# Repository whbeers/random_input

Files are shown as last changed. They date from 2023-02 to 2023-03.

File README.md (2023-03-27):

# Random Input Fuzz Effect

This is a re-creation of the original Dallas Arbiter Fuzz Face effect circuit, continuing my attempts to design guitar effects using [KiCAD](https://www.kicad.org/).

The resulting design is a product of breadboarding and experimentation after an initial build of the original circuit. It emphasizes the ability to easily fine-tune the bias of each transistor to obtain a pleasant sound from a variety of NPN transistors (germanium or silicon). Besides this emphasis, it remains true to the original.

The board is built on the ["Noise Floor"](https://github.com/whbeers/noise_floor) pedal platform, which provides basic power protection, audio IO, and a footswitch with LED indicator.

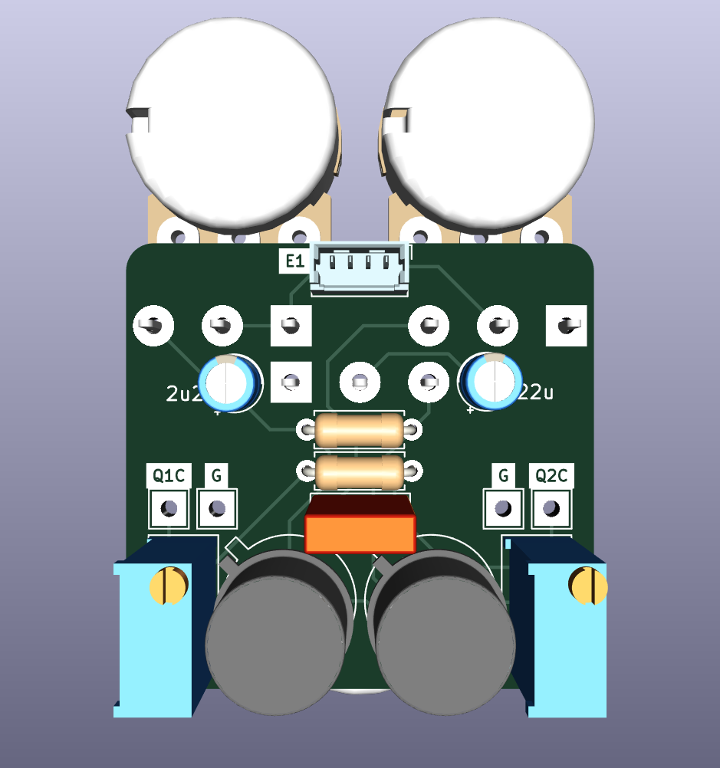
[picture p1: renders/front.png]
Front render

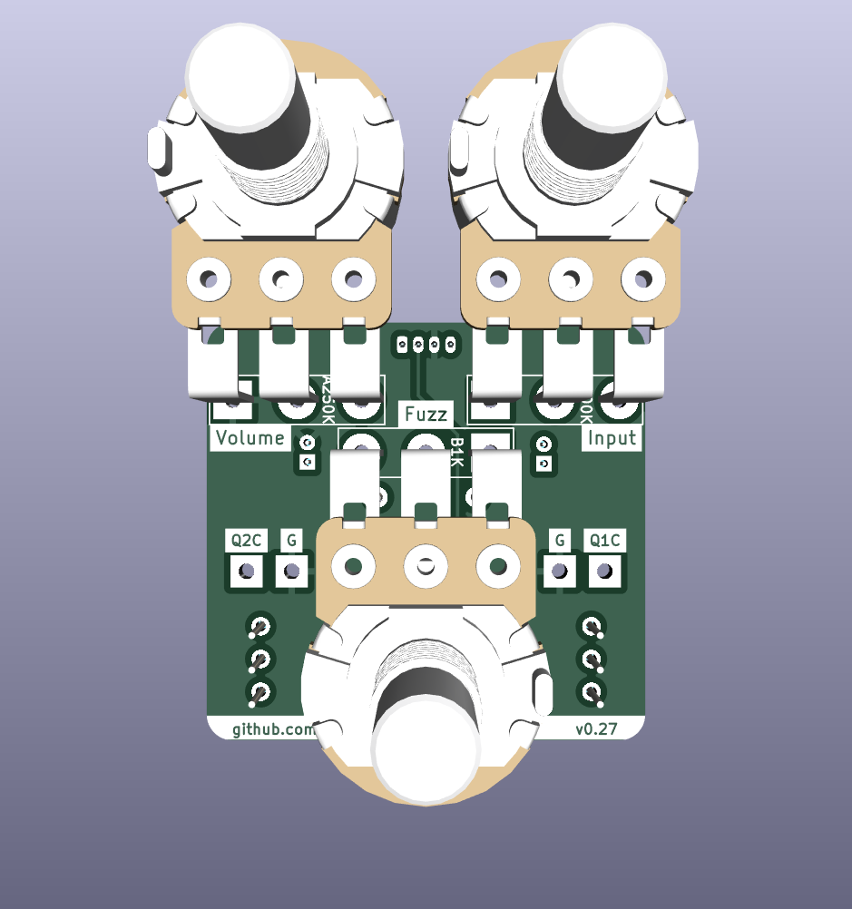
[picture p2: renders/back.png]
Back render

Schematic SVG
[Schematic PDF](schematics/random_input-latest.pdf)

Instructions for biasing transistors (using the incorporated trimpots) are provided in the schematic. (This was the approach that worked for me, after a few hours of research. I'm by no means an expert and would welcome feedback.)

## Credit
The basic schematic I worked from is widely available on the internet. At the same time my research drew on analyses from far-greater experts than myself, as well as published circuit diagrams. Most notably:
 - [CODA Effects' circuit analysis](https://www.coda-effects.com/p/circuit-analysis-fuzz-face.html)
 - [RG Keen's analysis](http://www.geofex.com/article_folders/fuzzface/fffram.htm)
 - [PedalPCB Twin Face](https://www.pedalpcb.com/product/twinface/)

Thanks as always to the folks on the [freestompboxes.org](https://www.freestompboxes.org/) forum for feedback and suggestions.

Potentiometer 3D model courtesy [Vasily Kashirin](https://grabcad.com/vasily.kashirin-1).

*I am not affiliated with any of the brands, sites, or products named in this overview.*

## Versioning

My pcb designs utilize the following versioning scheme (I'll add to this as I produce more revisions):
 - v0.0XX: A candidate design that has not yet been produced and tested.
 - v0.XX: A design that has been produced, tested, and any initial errors addressed.

## Name
*The name "Random Input" is a reflection of the nature of the effect (a very basic fuzz) and security nerdery (fuzzing software using random input being a primitive technique to surface errors).*

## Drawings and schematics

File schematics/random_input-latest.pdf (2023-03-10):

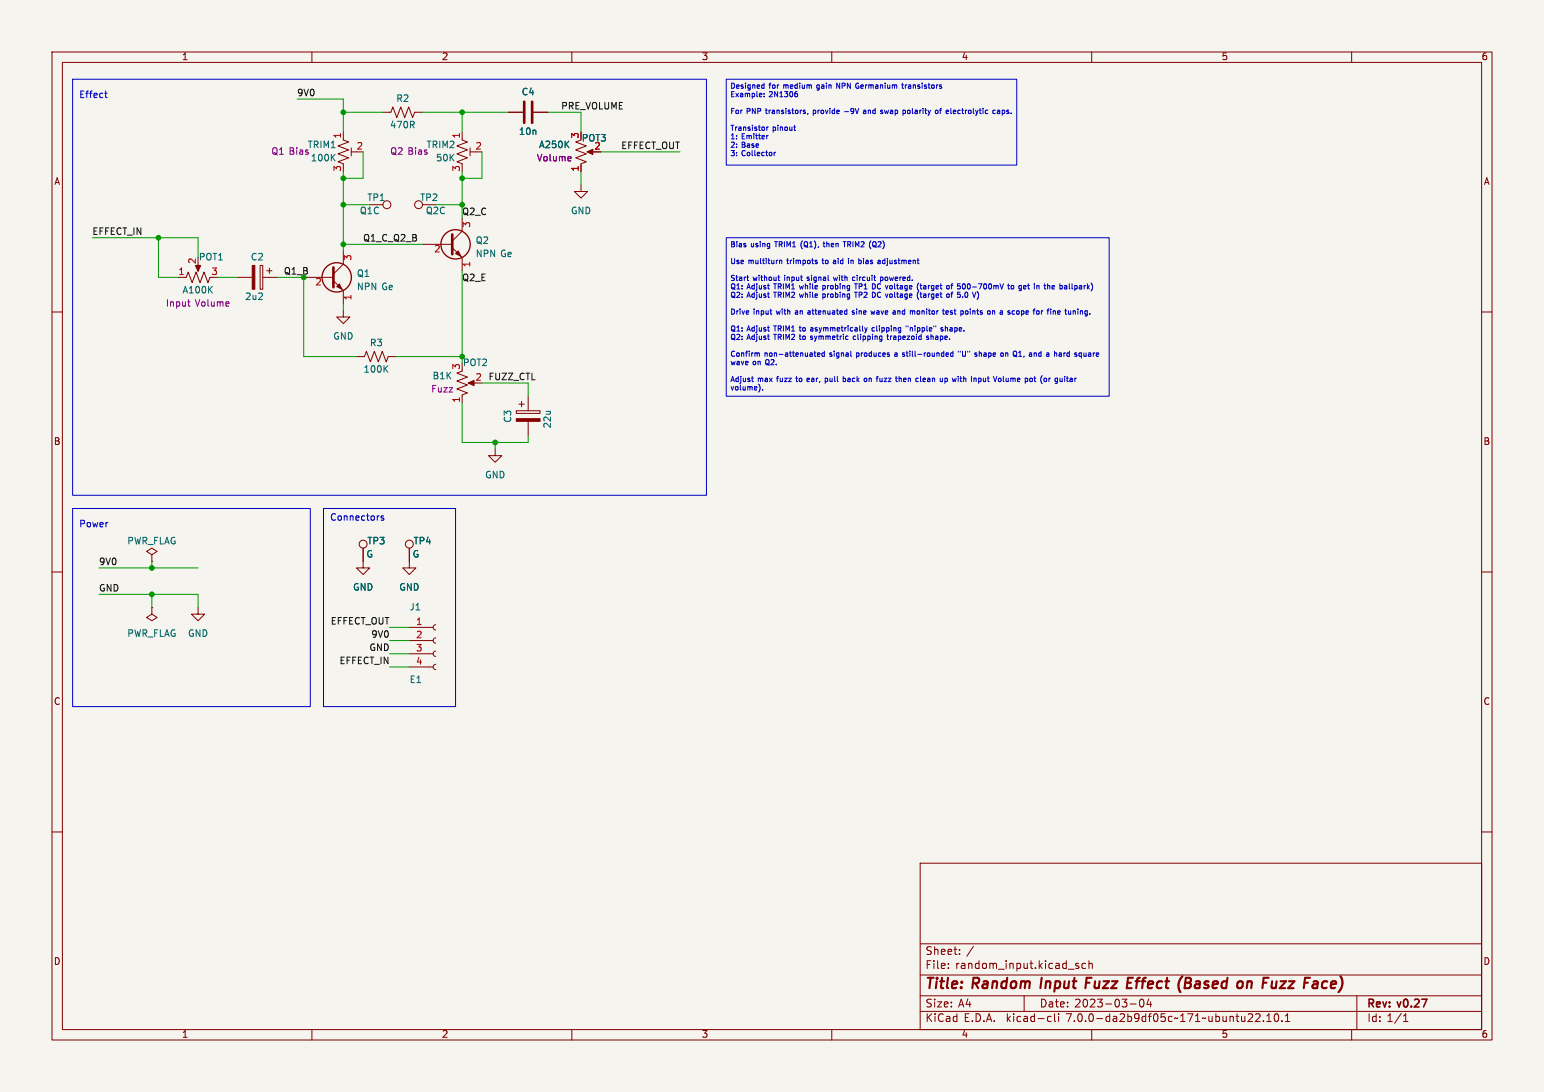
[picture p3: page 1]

Id: 1/1 Title: Random Input Fuzz Effect (Based on Fuzz Face) File: random_input.kicad_sch Sheet: /

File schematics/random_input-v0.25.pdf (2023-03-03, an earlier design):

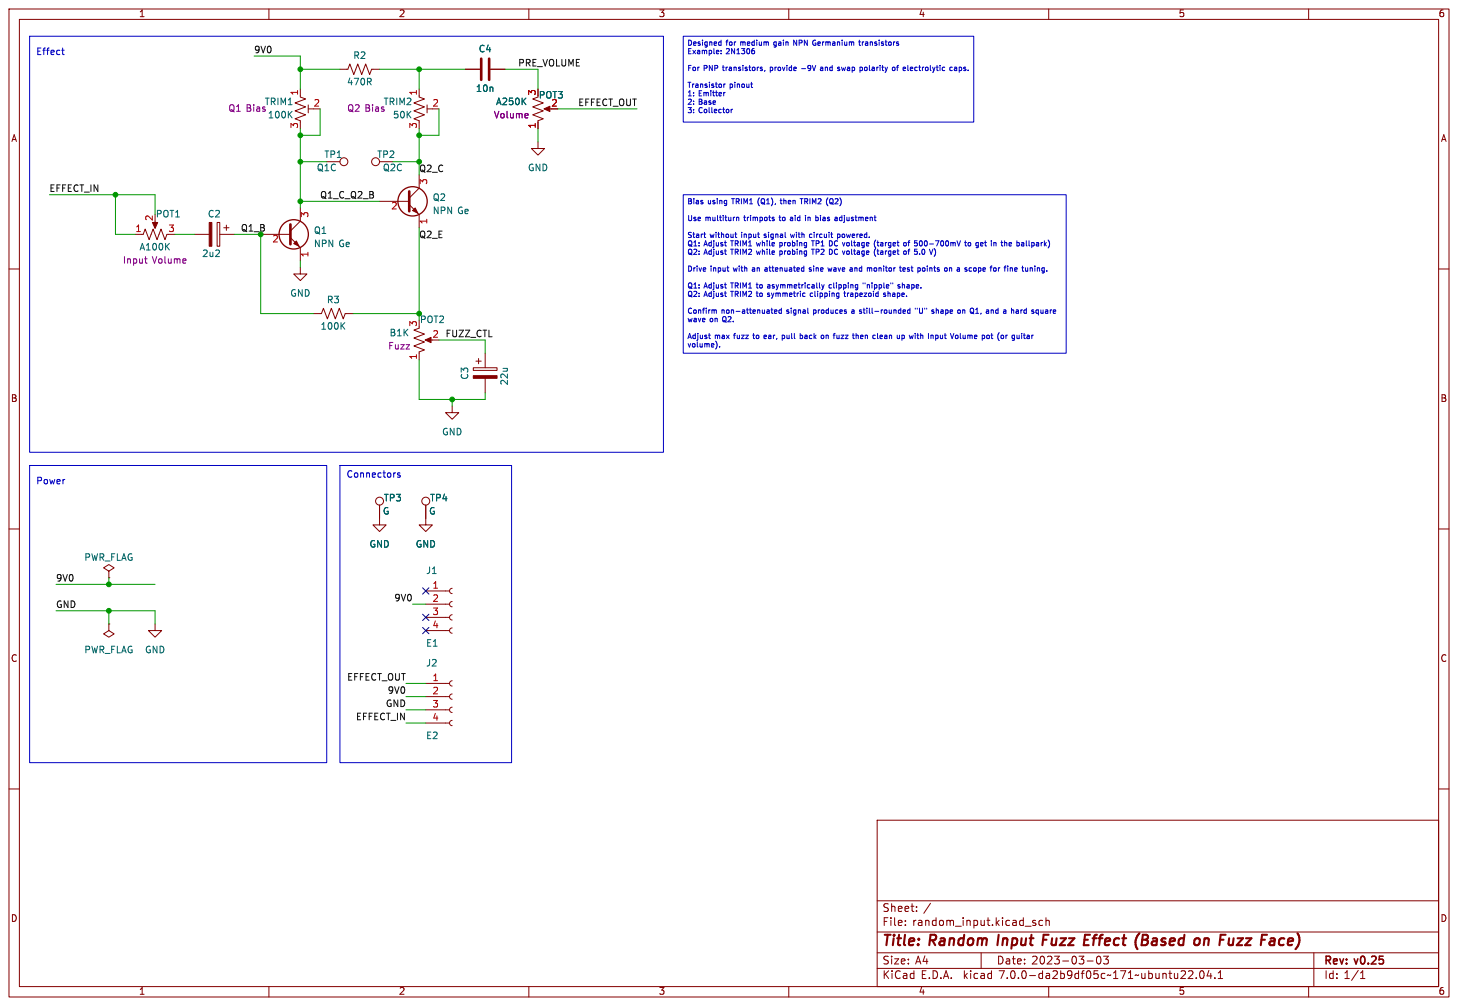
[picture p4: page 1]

Id: 1/1 Title: Random Input Fuzz Effect (Based on Fuzz Face) File: random_input.kicad_sch Sheet: /

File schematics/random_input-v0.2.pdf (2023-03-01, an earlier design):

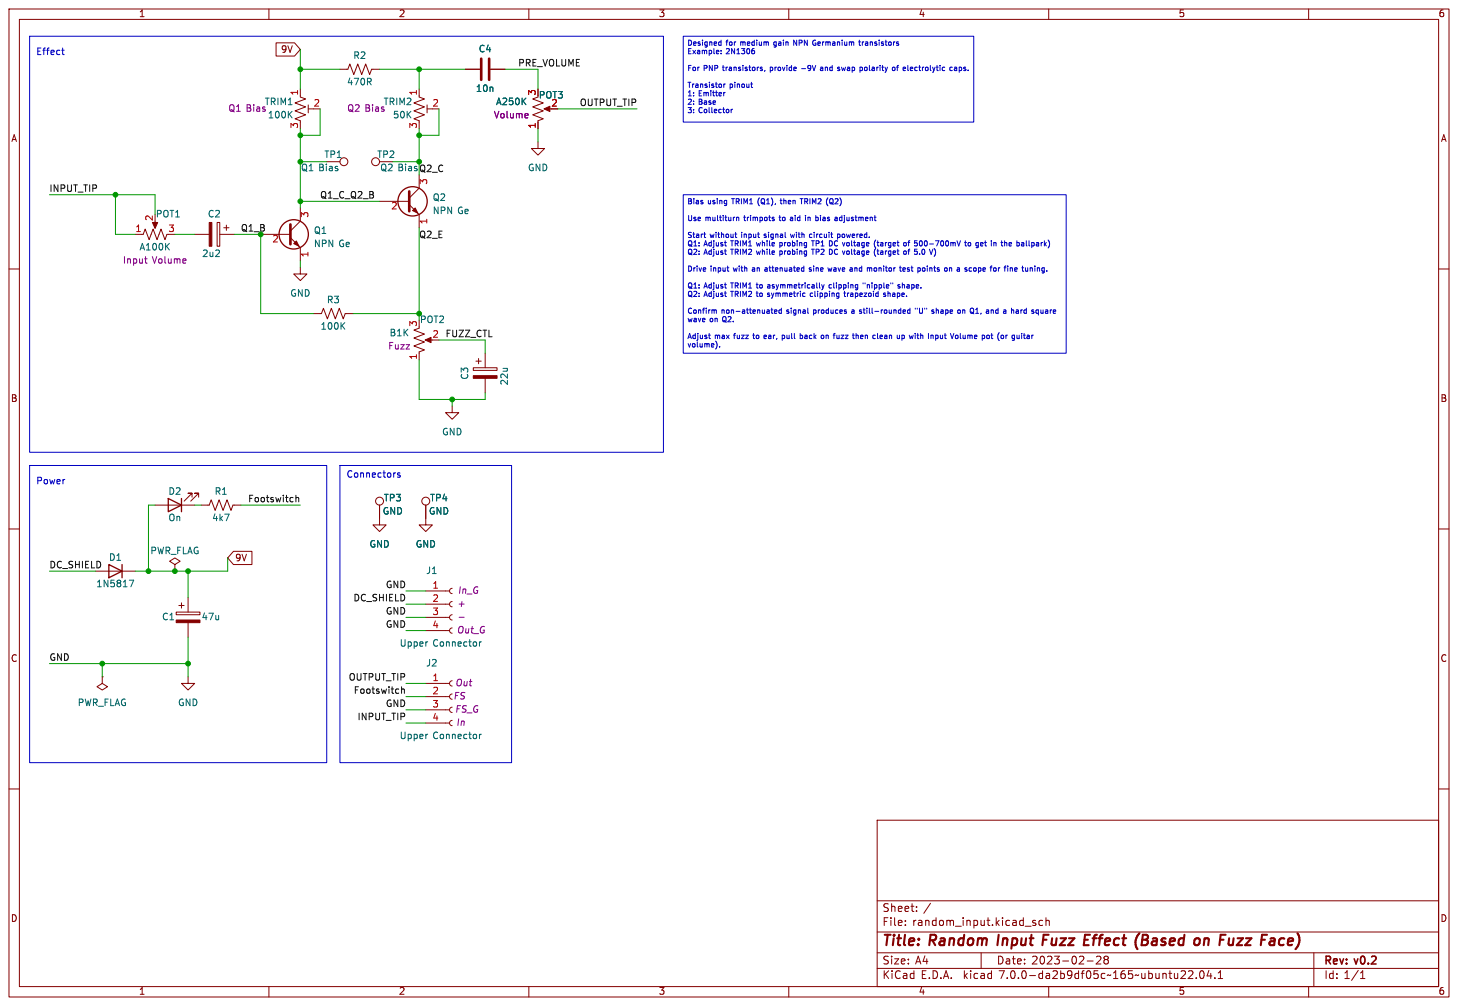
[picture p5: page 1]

Id: 1/1 Title: Random Input Fuzz Effect (Based on Fuzz Face) File: random_input.kicad_sch Sheet: /

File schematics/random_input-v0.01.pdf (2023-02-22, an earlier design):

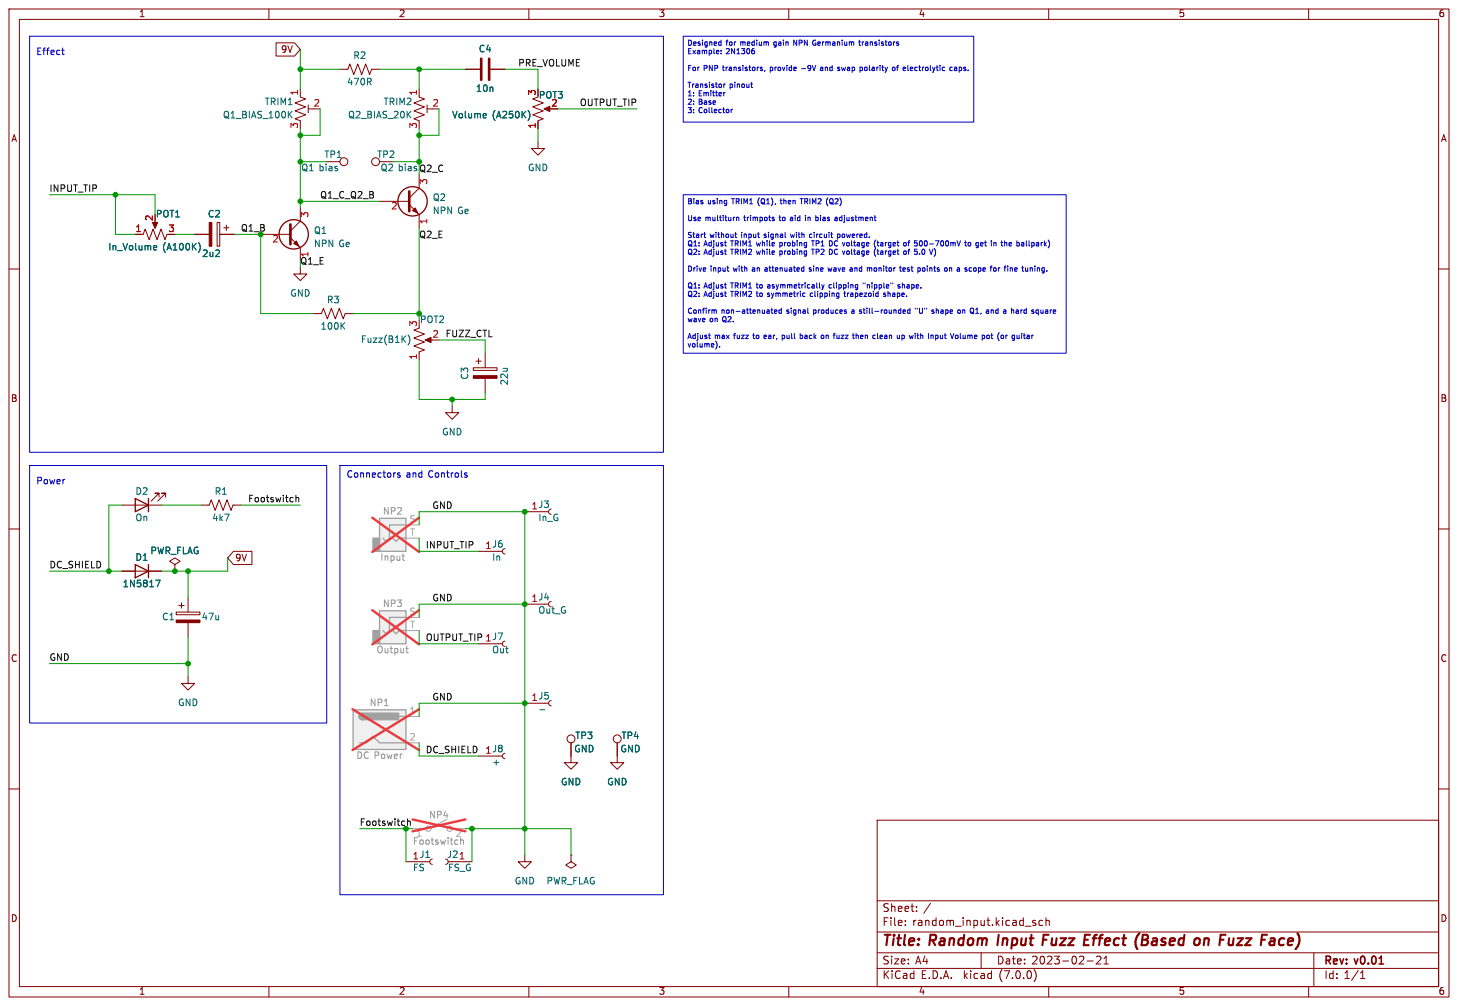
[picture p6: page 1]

Id: 1/1 Title: Random Input Fuzz Effect (Based on Fuzz Face) File: random_input.kicad_sch Sheet: /

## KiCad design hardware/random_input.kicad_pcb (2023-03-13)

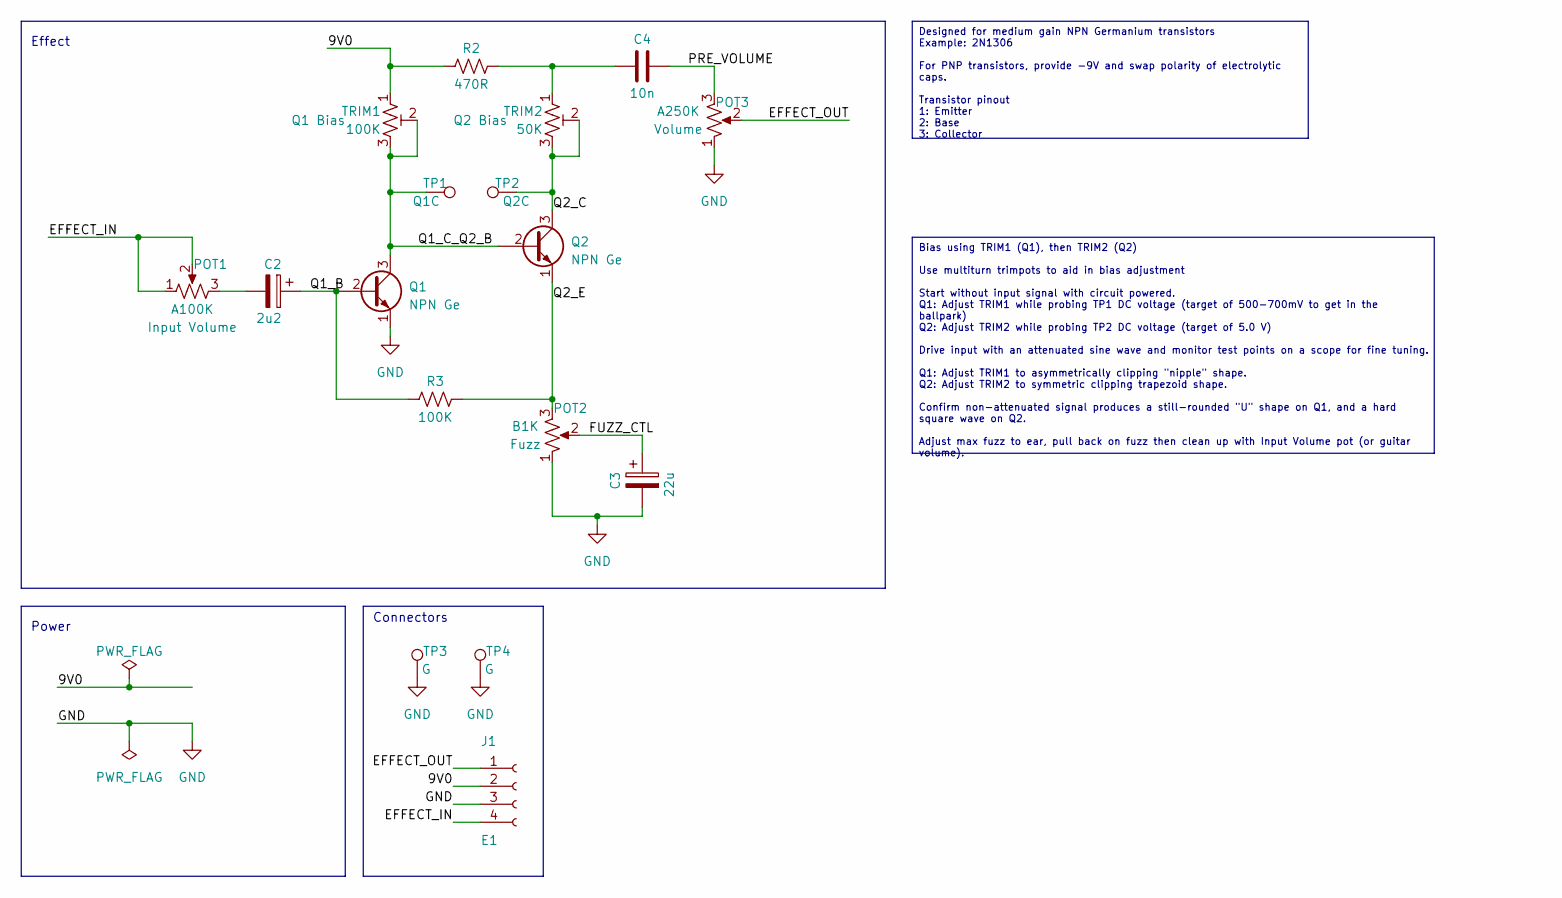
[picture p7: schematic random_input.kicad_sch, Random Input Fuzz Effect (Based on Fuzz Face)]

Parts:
C2: 2u2; CP_Radial_D4.0mm_P1.50mm
C3: 22u; CP_Radial_D4.0mm_P1.50mm
C4: 10n; C_Rect_L7.0mm_W2.5mm_P5.00mm
J1: E1; Molex_PicoBlade_53047-0410_1x04_P1.25mm_Vertical_with_3D_Mo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
POT1: A100K; Potentiometer_Single_3_Horizontal
POT2: B1K; Potentiometer_Single_3_Horizontal
POT3: A250K; Potentiometer_Single_3_Horizontal
Q1, Q2: NPN Ge; TO-5-3
R2: 470R; R_Axial_DIN0207_L6.3mm_D2.5mm_P7.62mm_Horizontal
R3: 100K; R_Axial_DIN0207_L6.3mm_D2.5mm_P7.62mm_Horizontal
TP1: Q1C; TestPoint_THTPad_2.5x2.5mm_Drill1.2mm
TP2: Q2C; TestPoint_THTPad_2.5x2.5mm_Drill1.2mm
TP3, TP4: G; TestPoint_THTPad_2.5x2.5mm_Drill1.2mm
TRIM1: 100K; Potentiometer_Bourns_3296W_Vertical
TRIM2: 50K; Potentiometer_Bourns_3296W_Vertical

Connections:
/9V0: J1.2, R2.1, TRIM1.1
/EFFECT_IN: J1.4, POT1.1, POT1.2
/EFFECT_OUT: J1.1, POT3.2
/FUZZ_CTL: C3.1, POT2.2
/PRE_VOLUME: C4.2, POT3.3
/Q1_B: C2.1, Q1.2 (B), R3.1
/Q1_C_Q2_B: Q1.3 (C), Q2.2 (B), TP1.1, TRIM1.2, TRIM1.3
/Q2_C: Q2.3 (C), TP2.1, TRIM2.2, TRIM2.3
/Q2_E: POT2.3, Q2.1 (E), R3.2
GND: C3.2, J1.3, POT2.1, POT3.1, Q1.1 (E), TP3.1, TP4.1
unnamed: C2.2, POT1.3
unnamed: C4.1, R2.2, TRIM2.1

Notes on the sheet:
Designed for medium gain NPN Germanium transistors Example: 2N1306 For PNP transistors, provide -9V and swap polarity of electrolytic caps. Transistor pinout 1: Emitter 2: Base 3: Collector
Bias using TRIM1 (Q1), then TRIM2 (Q2) Use multiturn trimpots to aid in bias adjustment Start without input signal with circuit powered. Q1: Adjust TRIM1 while probing TP1 DC voltage (target of 500-700mV to get in the ballpark) Q2: Adjust TRIM2 while probing TP2 DC voltage (target of 5.0 V) Drive i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
Effect
Power
Connectors

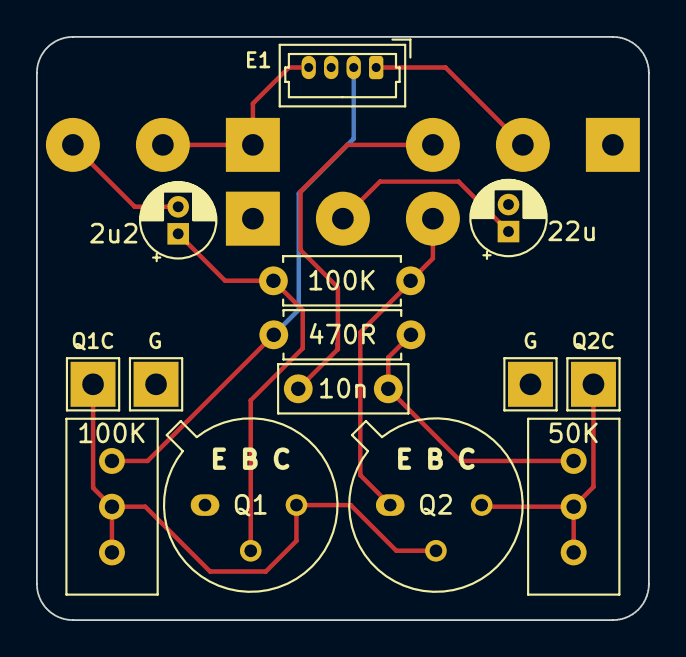
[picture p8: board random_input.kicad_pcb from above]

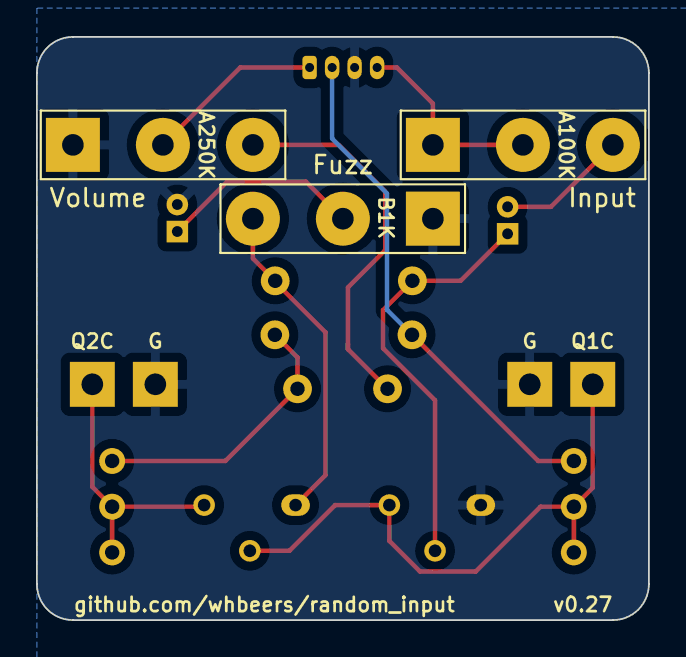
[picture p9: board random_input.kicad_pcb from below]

Board: 2 copper layers, 34.0 x 32.4 mm, 17 parts (3 on the bottom side), 12 nets.

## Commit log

2023-02-22 Update README.md
    fix schematic link and bullet list
2023-02-22 mostly cosmetic updates
    - add copper finish
    - move revision and web reference to a global variable
    - minor text updates
    [random_input.kicad_pcb]
2023-02-28 Address issues found in v0.01 hardware
    - Move all potentiometers to back copper layer (they were reversed)
    - cosmetic/usability updates
    - adjust value of Q2 trimpot to allow correct biasing
    - swap FS and FS_G wires
    [random_input.kicad_pcb, random_input.kicad_sch]
2023-03-01 Updates for v0.2:
    - Switch from wire connectors to molex picoblade connectors
    - Increase size / ergonomics of bias testing pads to suit more probe types
    - Various cosmetic fixes
    [random_input.kicad_pcb, random_input.kicad_sch]
2023-03-03 Offload DC protection to "noise floor" utility PCB
    - much rerouting but otherwise functionally the same
    [random_input.kicad_pcb, random_input.kicad_sch]
2023-03-03 rename schematic file with version number
2023-03-03 bump version number on schematic, oops
    [random_input.kicad_sch]
2023-03-03 Drop to a single connector to simplify, bump rev to v0.26
    [random_input.kicad_pcb, random_input.kicad_sch]
2023-03-04 Some updates based on feedback from freestompboxes.org folks:
    - Add back thermal reliefs on ground pads
    - Add 3D models for various parts (courtesy of Vasily Kashirin - https://grabcad.com/vasily.kashirin-1/models?page=1)
    [random_input.kicad_pcb, random_input.kicad_sch]
2023-03-04 fix a couple DRCs
    [random_input.kicad_pcb]
2023-03-05 add script to generate schematic, saving time at release. also embed an SVG schematic in README.
2023-03-05 add script to export gerbers and drill files
2023-03-10 update schematic plotting script to create the directory if it doesn't exist
2023-03-10 generate new schematic (although nothing should have updated)
2023-03-13 Update to latest stable kicad version:
    - fixed issue rendering certain 3d models in color
    - had to fix some text rendering changes
    [random_input.kicad_pcb]
